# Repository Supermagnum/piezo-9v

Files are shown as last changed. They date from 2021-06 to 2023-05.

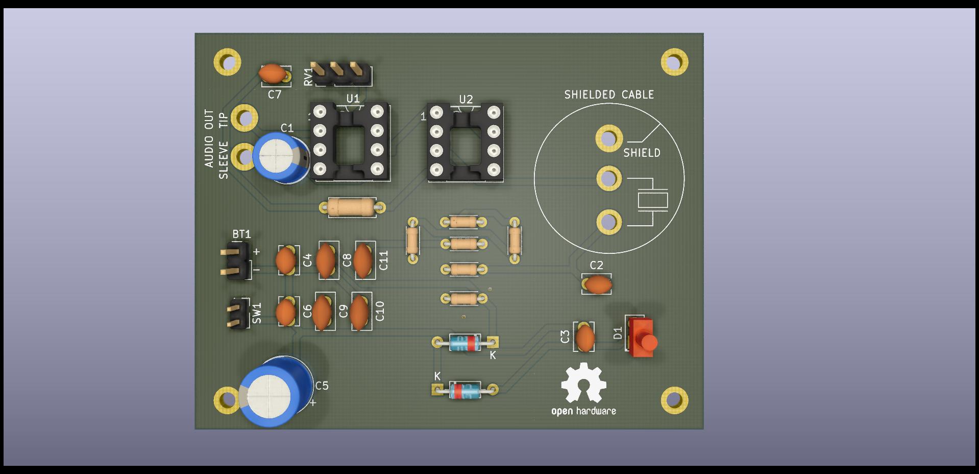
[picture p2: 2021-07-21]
9v-preamp-components.jpg

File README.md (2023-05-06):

# piezo-9v
A small PCB for pizoelectric amplifier, runs on 9V.
It should have battery capacity for around 5 hours.

It's fairly easy and straight forward to solder the components to the circuit board, a nice pointy soldering iron, solder,and a ohm or multimeter is all that is needed. 

Please use 0,5 W metal film resistors with 1% tolerance or better and audio quality capacitors.
C0G (NP0) or X7R capacitors is very good.

Of course one needs a suitable metal box, and the circuit boards components must not come in contact with the metal box. 
That will cause short circuit, so it's best mounted on conducting stand offs because the corner pads on the PCB board must be connected to the metal box.
Check that no one of the soldering pads has been bridged before applying power.

A shielded cable must be used to connect to the piezoelectric element.
NOTE:
It is my opinion that a shielded cable with 2 conductors inside is the best.
Suggested cable: Digi-Key Part Number: 30-01225-5-ND

The sensivity can be made adjustable if a rotary potentiometer is used to replace R7.
A nice one is : Digi-Key Part Number 310Y-001-103L-ND. 
Connect one end of the terminals to one of the R7 solder points, and the middle terminal to the other. 

It can be used for a reverb plate, listening to the insides of a engine,recording the sound of vibrating things. 
You will need one piezoelectric disk for that, mounted in a metal box made of thin metal. Non electric conductive super glue is useable for that. 
Just glue it to a flat surface. 
The piezoelectric disk should be electrically insulated from the metal box.

Picture of a piezoelectric disc, with red wire for positive polarity and black for negative: https://github.com/Supermagnum/piezo-balanced/blob/main/Piezo-element-6.jpg

Schematic diagram:
https://github.com/Supermagnum/piezo-9v/blob/main/9v-preamp.pdf
D1 is a LED that lights up when it's switched on.

Aisler PCB:
https://aisler.net/p/BZUXMWVU

Digikey part list:
https://github.com/Supermagnum/piezo-9v/blob/main/9vpiezo-digikey-BOM.csv
(does NOT include the PCB or the necessary two conductor shielded cable to the piezoelectric element)

Component side of PCB:
https://github.com/Supermagnum/piezo-9v/blob/main/front.jpg

Back side:
https://github.com/Supermagnum/piezo-9v/blob/main/back.jpg

Picture with sockets for the opamps, capacitators,resistors and diodes installed:
https://github.com/Supermagnum/piezo-9v/blob/main/9v-preamp-components.jpg

Gerber files:
https://github.com/Supermagnum/piezo-9v/tree/main/gerbers

Some methods of mounting a piezoelectric disk can be found here:
https://locusonus.org/wiki/index.php?page=Hydrophone.en
Use a metal box with thin walls.
Commercial ones uses kerosene oil, so olive oil or sunflower oil is a great alternative as it will not pollute the environment if any leaks occurs. Aquarium silicone can also be used.
For flowing water a streamlined bulb is best, it reduces flow noise.

Around 35 to 40 dB gain should be nice for hydrophone usage.

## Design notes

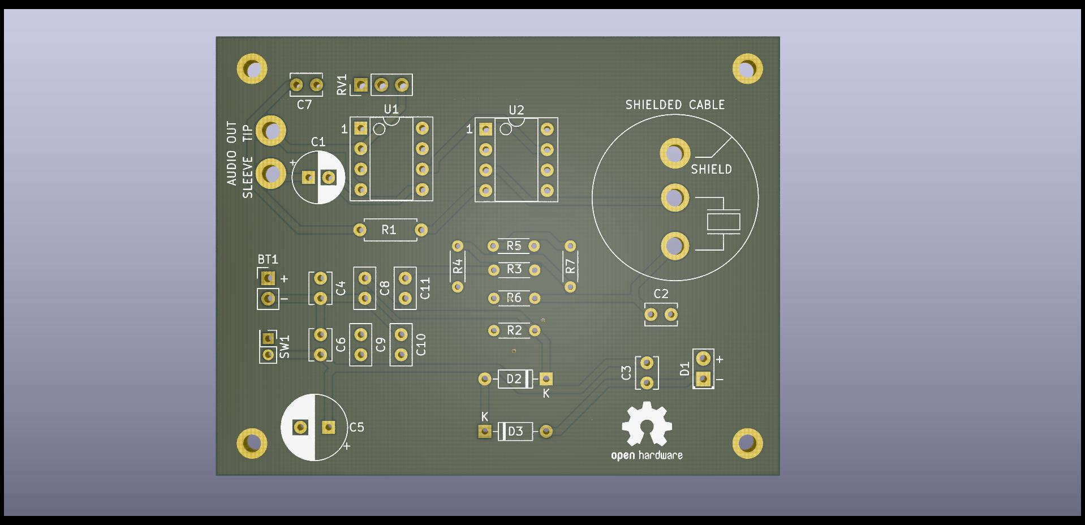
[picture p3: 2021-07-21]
front.jpg

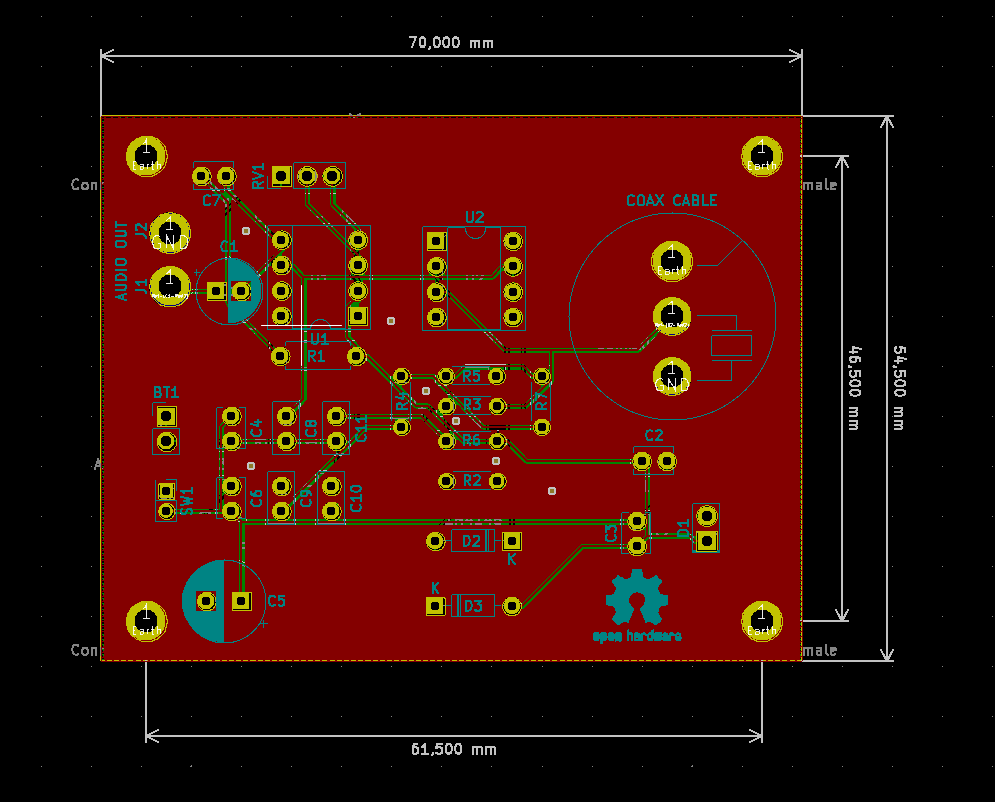
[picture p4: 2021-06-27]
Dimentions.png

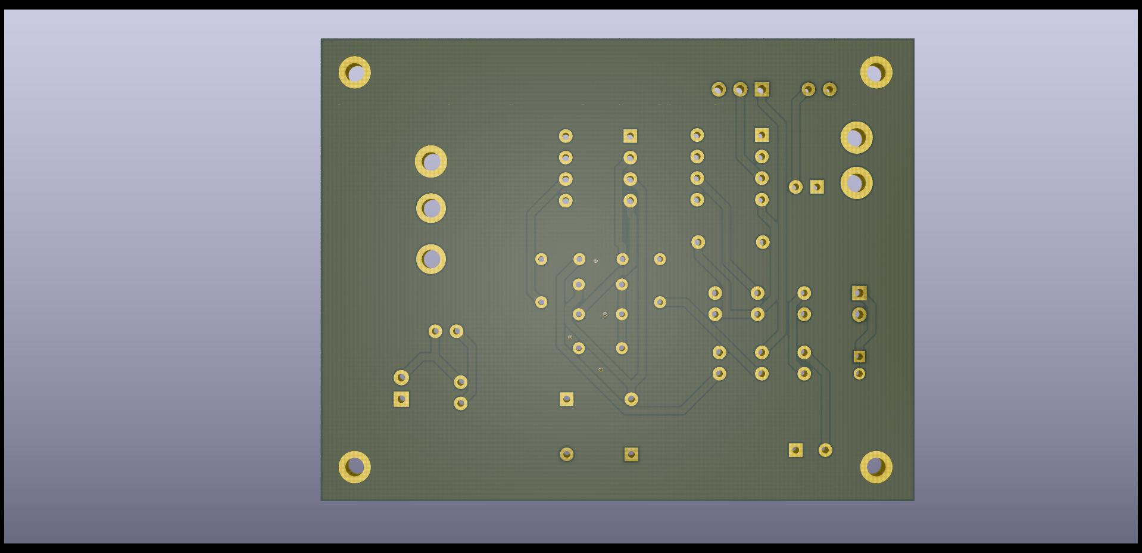
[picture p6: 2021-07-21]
back.jpg

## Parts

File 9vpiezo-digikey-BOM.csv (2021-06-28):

Index | Manufacturer Part Number | Manufacturer Name | Description | Attrition % | Requested Quantity 1 | Pack Quantity 1 | Pack Type 1 | Digi-Key Part Number 1 | Unit Price 1 | Extended Price 1 | Minimum Order Quantity 1 | Part Status
1 | NE5534P | Texas Instruments | IC OPAMP GP 1 CIRCUIT 8DIP |  | 1 | 1 | Tube | 296-7043-5-ND | 9,31000 | kr 9,31 | 1 | Active
2 | LM386N-4/NOPB | Texas Instruments | IC AMP CLASS AB MONO 1W 8DIP |  | 1 | 1 | Tube | 296-43960-5-ND | 11,16000 | kr 11,16 | 1 | Active
3 | P120PK-Y25BR10K | TT Electronics/BI | POT 10K OHM 1/20W PLASTIC LINEAR |  | 1 | 1 | Tray | 987-1710-ND | 5,79000 | kr 5,79 | 1 | Active
4 | 5100H7FL | Visual Communications Company - VCC | LED YELLOW 1/4" HOLE PANEL MOUNT |  | 1 | 1 | Bulk | L20697-ND | 38,01000 | kr 38,01 | 1 | Active
5 | 7105D | Electroswitch | SWITCH TOGGLE SPST 6A 125V |  | 1 | 1 | Bulk | 451-1158-ND | 31,63000 | kr 31,63 | 1 | Active
6 | FG22X5R1A476MNT06 | TDK Corporation | CAP CER 47UF 10V X5R RADIAL |  | 2 | 2 | Cut Tape (CT) | 445-173314-1-ND | 12,17000 | kr 24,34 | 1 | Active
7 | MRS16000C5602FCT00 | Vishay Beyschlag/Draloric/BC Components | RES 56K OHM 0.4W 1% AXIAL |  | 2 | 2 | Cut Tape (CT) | 56-MRS16000C5602FCT00CT-ND | 1,93000 | kr 3,86 | 1 | Active
8 | 1N4148-G | Comchip Technology | DIODE GEN PURP 75V 150MA DO35 |  | 2 | 2 | Cut Tape (CT) | 641-1313-1-ND | 1,43000 | kr 2,86 | 1 | Active
9 | C320C106K3R5TA | KEMET | CAP CER RAD 10UF 25V X7R 10% |  | 1 | 1 | Bulk | C320C106K3R5TA-ND | 29,20000 | kr 29,20 | 1 | Active
10 | C320C102K3G5TA | KEMET | CAP CER RAD 1NF 25V C0G 10% |  | 1 | 1 | Bulk | C320C102K3G5TA-ND | 3,61000 | kr 3,61 | 1 | Active
11 | PLV1D221MDL1TD | Nichicon | CAP ALUM POLY 220UF 20% 20V T/H |  | 1 | 1 | Cut Tape (CT) | 493-3861-1-ND | 23,66000 | kr 23,66 | 1 | Active
12 | CF12JT470R | Stackpole Electronics Inc | RES 470 OHM 1/2W 5% AXIAL |  | 1 | 1 | Cut Tape (CT) | CF12JT470RCT-ND | 0,84000 | kr 0,84 | 1 | Active
13 | RNF14FTD100R | Stackpole Electronics Inc | RES 100 OHM 1/4W 1% AXIAL |  | 1 | 1 | Cut Tape (CT) | RNF14FTD100RCT-ND | 0,84000 | kr 0,84 | 1 | Active
14 | RNF14FTD10R0 | Stackpole Electronics Inc | RES 10 OHM 1/4W 1% AXIAL |  | 1 | 1 | Cut Tape (CT) | RNF14FTD10R0CT-ND | 0,84000 | kr 0,84 | 1 | Active
15 | RL81V101MDN1KX | Nichicon | CAP ALUM POLY 100UF 20% 35V T/H |  | 1 | 1 | Cut Tape (CT) | 493-6630-1-ND | 17,79000 | kr 17,79 | 1 | Active
16 | FA16C0G2A104JRU06 | TDK Corporation | CAP CER 100NF 100V C0G/NP0 RAD |  | 1 | 1 | Cut Tape (CT) | 445-175390-1-ND | 10,49000 | kr 10,49 | 1 | Active
17 | FK20X7S1H475KR000 | TDK Corporation | CAP CER 4.7UF 50V X7S RADIAL |  | 1 | 1 | Bulk | 445-FK20X7S1H475KR000-ND | 7,47000 | kr 7,47 | 1 | Not For New Designs
18 | K104K10X7RF5UH5 | Vishay Beyschlag/Draloric/BC Components | CAP CER 0.1UF 50V X7R RADIAL |  | 1 | 1 | Cut Tape (CT) | BC2665CT-ND | 1,93000 | kr 1,93 | 1 | Active
19 | S503Z69Z5UL63L0R | Vishay Beyschlag/Draloric/BC Components | CAP CER 0.05UF 500V Z5U RADIAL |  | 1 | 1 | Bulk | BC5192-ND | 9,90000 | kr 9,90 | 1 | Active
20 | FG26X5R1E336MRT06 | TDK Corporation | CAP CER 33UF 25V X5R RADIAL |  | 1 | 1 | Cut Tape (CT) | 445-173432-1-ND | 8,56000 | kr 8,56 | 1 | Active
21 | HH-3449 | Bud Industries | BATTERY CONNECT SNAP 9V 6" LEADS |  | 1 | 1 | Bag | 377-1549-ND | 10,91000 | kr 10,91 | 1 | Active
22 | AB2025B-LW100-R | PUI Audio, Inc. | BUZZER ELEMENT STD 2.5KHZ 20MM |  | 2 | 2 | Bag | 668-1403-ND | 13,76000 | kr 27,52 | 1 | Active
23 | 1-2199298-2 | TE Connectivity AMP Connectors | CONN IC DIP SOCKET 8POS TIN |  | 2 | 2 | Tube | A120347-ND | 1,51000 | kr 3,02 | 1 | Active
24 | VR25000001004FA500 | Vishay Beyschlag/Draloric/BC Components | RES 1M OHM 1% 1/4W AXIAL |  | 1 | 1 | Cut Tape (CT) | BC4867CT-ND | 3,52000 | kr 3,52 | 1 | Active
25 | MBA02040C4701FCT00 | Vishay Beyschlag/Draloric/BC Components | RES 4.7K OHM 0.4W 1% AXIAL |  | 1 | 1 | Cut Tape (CT) | BC3275CT-ND | 1,85000 | kr 1,85 | 1 | Active
26 | MJ-3536N | CUI Devices | CONN JACK MONO 3.5MM R/A |  | 1 | 1 | Bag | CP-3536N-ND | 6,80000 | kr 6,80 | 1 | Active

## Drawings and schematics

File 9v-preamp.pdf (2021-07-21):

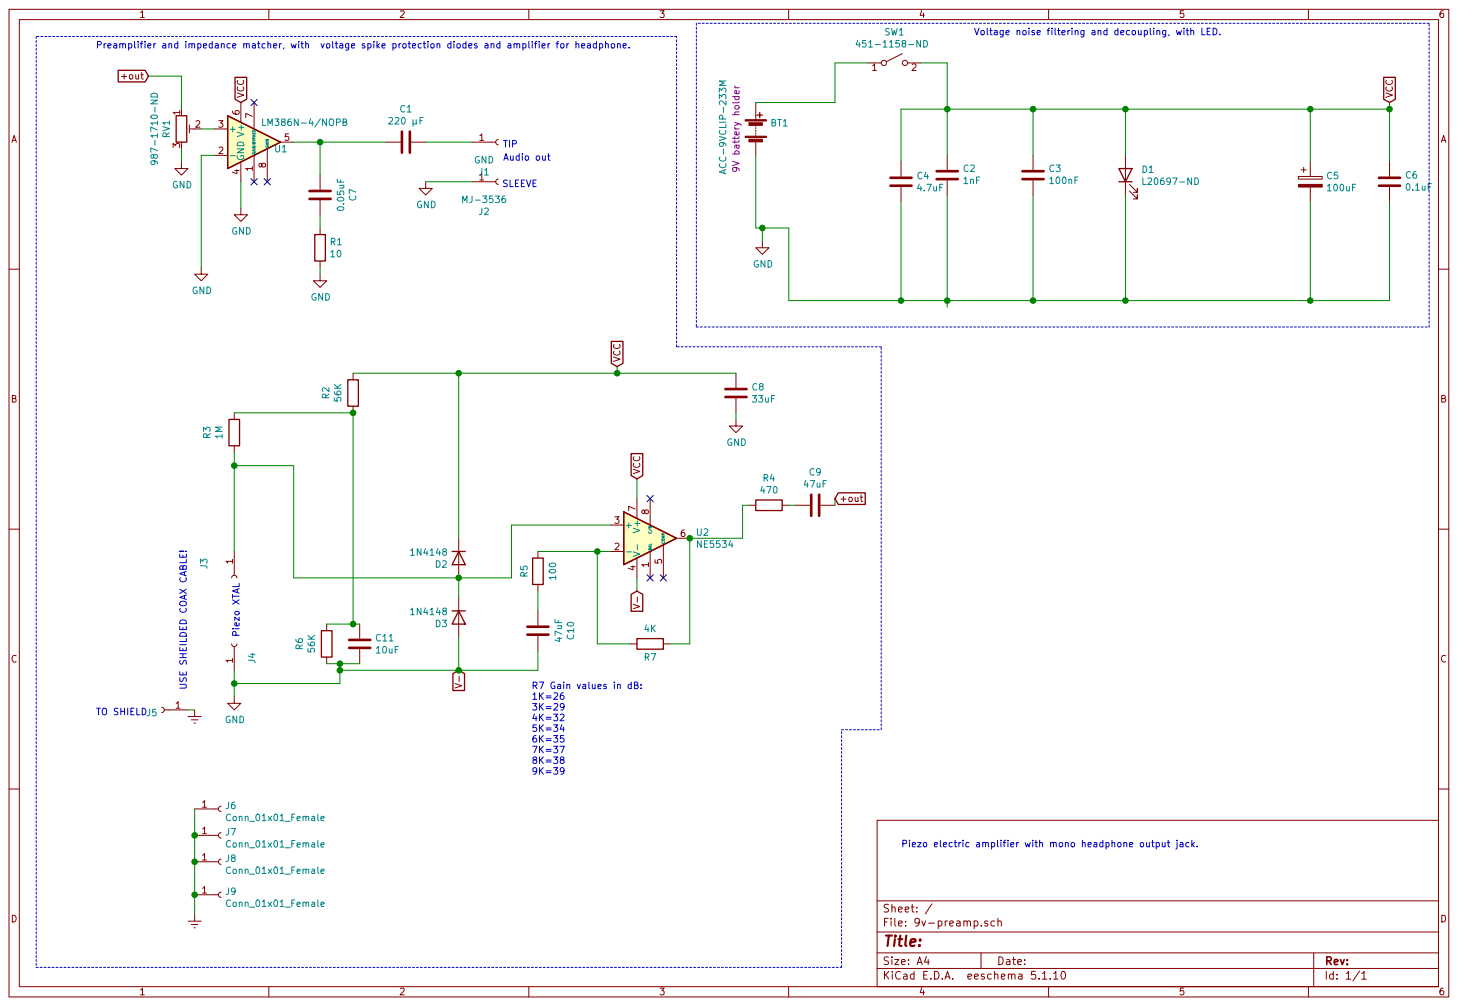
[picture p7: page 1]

Preamplifier and impedance matcher, with voltage spike protection diodes and amplifier for headphone. Piezo XTAL

Piezo electric amplifier with mono headphone output jack.

File: 9v-preamp.sch Sheet: /
Id: 1/1 Title:

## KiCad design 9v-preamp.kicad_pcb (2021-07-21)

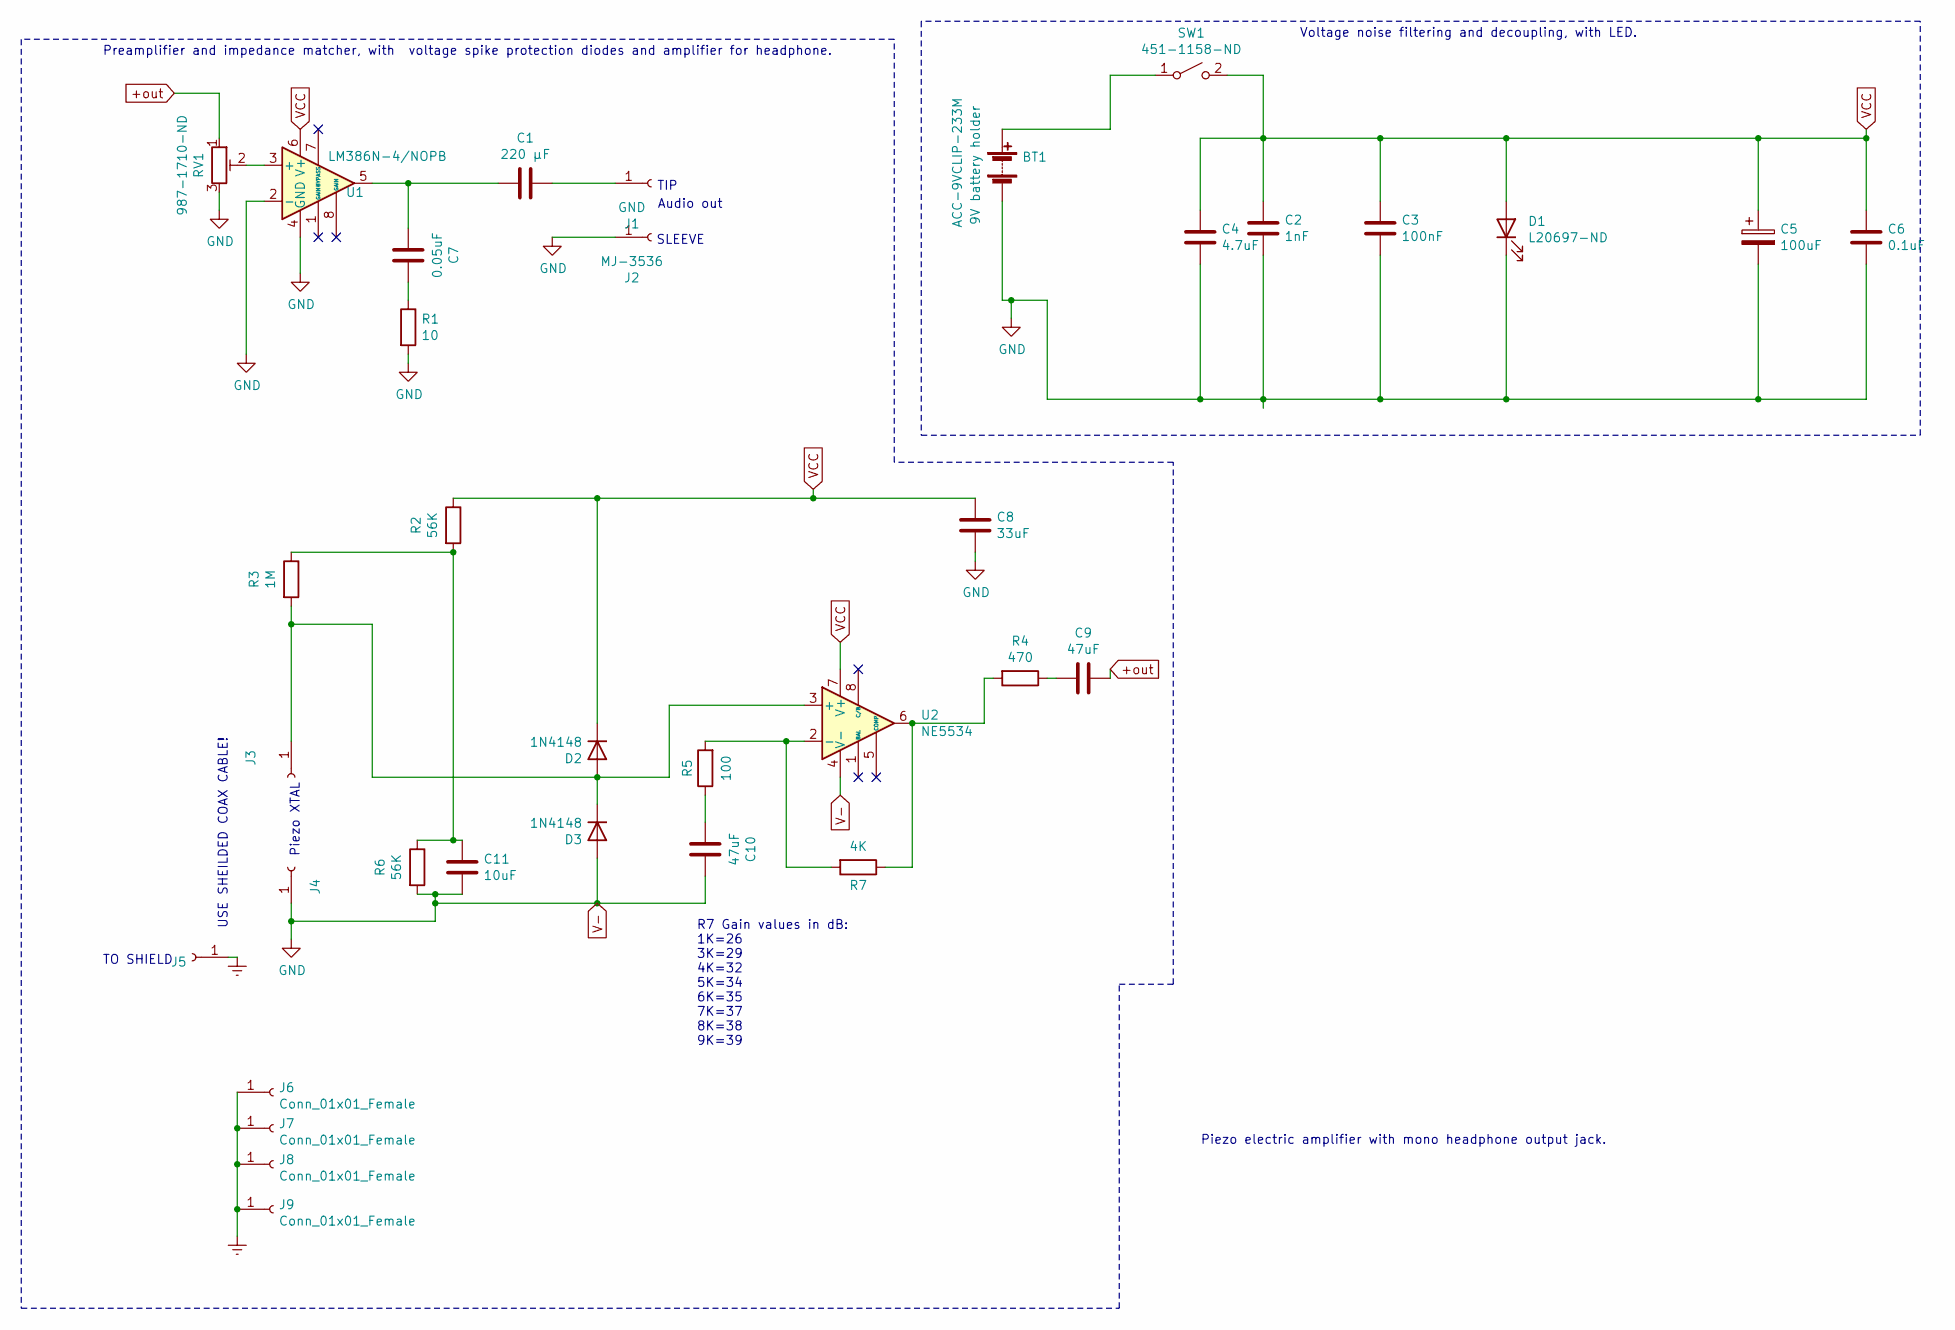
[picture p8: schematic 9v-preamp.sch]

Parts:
BT1: ACC-9VCLIP-233M; PinHeader_1x02_P2.54mm_Vertical
C1: 220 µF; CP_Radial_D6.3mm_P2.50mm
C2: 1nF; C_Disc_D3.8mm_W2.6mm_P2.50mm
C3: 100nF; C_Disc_D3.8mm_W2.6mm_P2.50mm
C4: 4.7uF; C_Disc_D3.8mm_W2.6mm_P2.50mm
C5: 100uF; CP_Radial_D8.0mm_P3.50mm
C6: 0.1uF; C_Disc_D3.8mm_W2.6mm_P2.50mm
C7: 0.05uF; C_Disc_D3.8mm_W2.6mm_P2.50mm
C8: 33uF; C_Disc_D5.0mm_W2.5mm_P2.50mm
C9, C10: 47uF; C_Disc_D5.0mm_W2.5mm_P2.50mm
C11: 10uF; C_Disc_D5.0mm_W2.5mm_P2.50mm
D1: L20697-ND; LED_D2.0mm_W4.8mm_H2.5mm_FlatTop
D2, D3: 1N4148; D_DO-35_SOD27_P7.62mm_Horizontal
J1: GND; MountingHole_2.2mm_M2_DIN965_Pad
J2: MJ-3536; MountingHole_2.2mm_M2_DIN965_Pad
J3, J4: Conn_01x01_Female; MountingHole_2.2mm_M2_ISO7380_Pad
J5, J6, J7, J8, J9: Conn_01x01_Female; MountingHole_2.2mm_M2_DIN965_Pad
R1: 10; R_Axial_DIN0207_L6.3mm_D2.5mm_P7.62mm_Horizontal
R2, R6: 56K; R_Axial_DIN0204_L3.6mm_D1.6mm_P5.08mm_Horizontal
R3: 1M; R_Axial_DIN0204_L3.6mm_D1.6mm_P5.08mm_Horizontal
R4: 470; R_Axial_DIN0204_L3.6mm_D1.6mm_P5.08mm_Horizontal
R5: 100; R_Axial_DIN0204_L3.6mm_D1.6mm_P5.08mm_Horizontal
R7: 4K; R_Axial_DIN0204_L3.6mm_D1.6mm_P5.08mm_Horizontal
RV1: 987-1710-ND; PinHeader_1x03_P2.54mm_Vertical
SW1: 451-1158-ND; PinHeader_2x01_P2.00mm_Vertical
U1: LM386N-4/NOPB; DIP-8_W7.62mm_Socket
U2: NE5534; DIP-8_W7.62mm_Socket

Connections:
+out: C9.1, RV1.1
Earth: J5.1, J6.1, J7.1, J8.1, J9.1
unnamed: BT1.1 (+), SW1.1 (A)
unnamed: C1.1, J1.1
unnamed: C1.2, C7.2, U1.5
unnamed: C7.1, R1.1
unnamed: C9.2, R4.1
unnamed: C10.2, R5.1
unnamed: C11.1, R2.2, R3.1, R6.1
unnamed: D2.2 (A), D3.1 (K), J3.1, R3.2, U2.3 (+)
unnamed: R4.2, R7.1, U2.6
unnamed: R5.2, R7.2, U2.2 (-)
unnamed: RV1.2, U1.3 (+)
V-: BT1.2 (-), C2.1, C3.1, C4.2, C5.2, C6.1, C8.2, C10.1, C11.2, D1.1 (K), D3.2 (A), J2.1, J4.1, R1.2, R6.2, RV1.3, U1.2 (-), U1.4 (GND), U2.4 (V-)
VCC: C2.2, C3.2, C4.1, C5.1, C6.2, C8.1, D1.2 (A), D2.1 (K), R2.1, SW1.2 (B), U1.6 (V+), U2.7 (V+)

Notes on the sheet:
Piezo electric amplifier with mono headphone output jack.
Audio out
TIP
SLEEVE
Piezo XTAL
R7 Gain values in dB: 1K=26 3K=29 4K=32 5K=34 6K=35 7K=37 8K=38 9K=39
USE SHEILDED COAX CABLE!
TO SHIELD
Voltage noise filtering and decoupling, with LED.
Preamplifier and impedance matcher, with voltage spike protection diodes and amplifier for headphone.

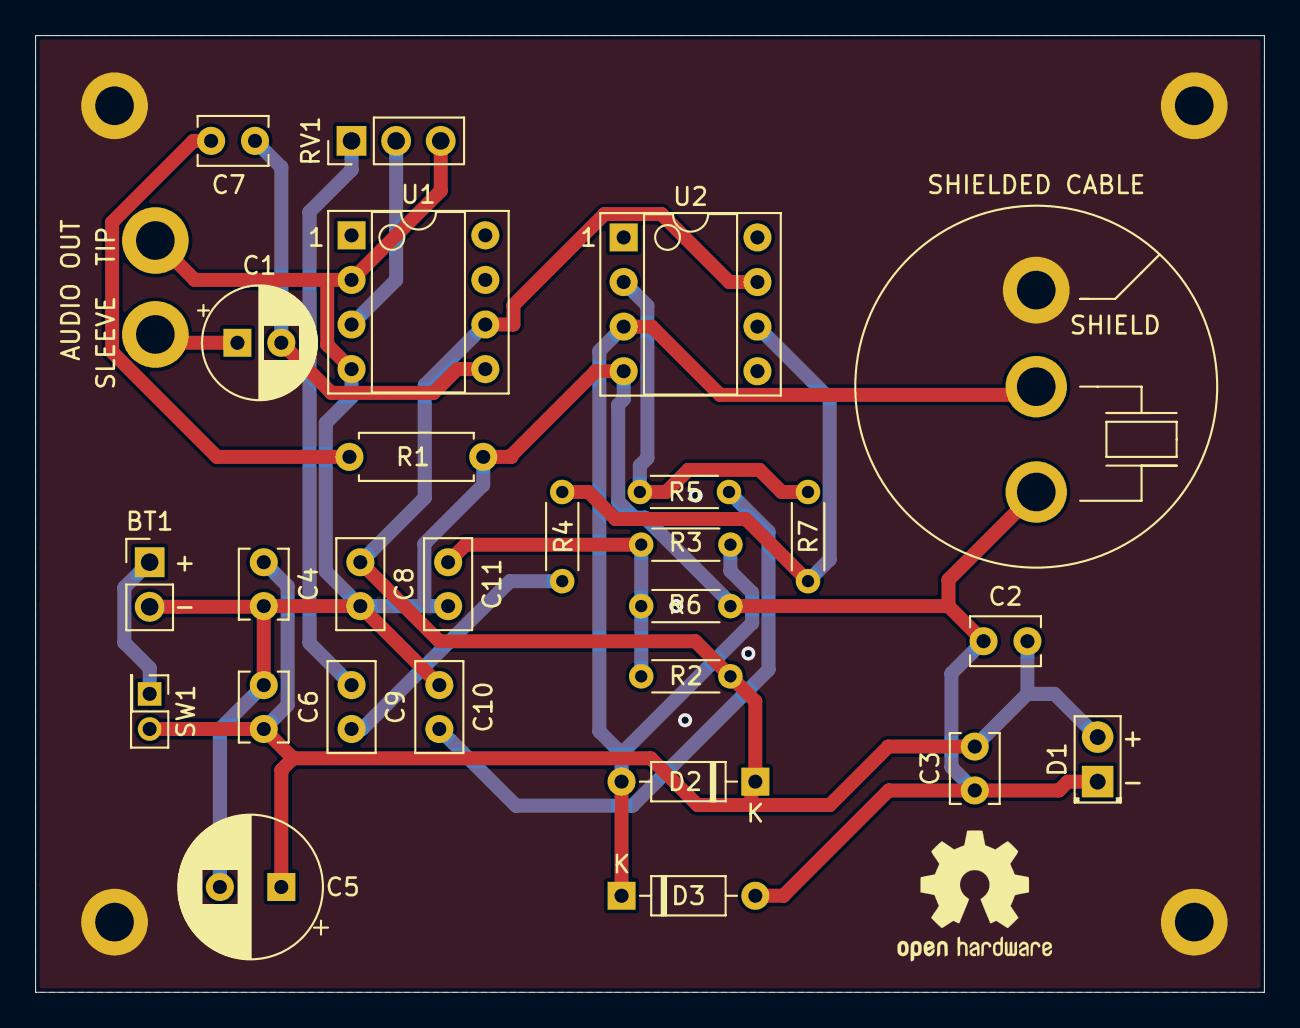
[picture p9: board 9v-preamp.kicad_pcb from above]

Board: 2 copper layers, 70.0 x 54.5 mm, 35 parts (0 on the bottom side), 15 nets.

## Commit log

2021-06-28 Add files via upload
    updated files, turned U1 around so It faces the same way as U2.
    [9v-preamp-B_Cu.gbr, 9v-preamp-B_Mask.gbr, 9v-preamp-B_Paste.gbr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]
2021-06-28 Added digikey part list.
    [9vpiezo-digikey-BOM.csv]
2021-07-02 Add files via upload
    corrected missing connection to VCC.
    [9v-preamp-B_Cu.gbr, 9v-preamp-B_Mask.gbr, 9v-preamp-B_Paste.gbr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]
2021-07-21 Add files via upload
    Added + and - marks on the LED solder connections, and pin 1 on the op amps.
    [9v-preamp-B_Cu.gbr, 9v-preamp-B_Mask.gbr, 9v-preamp-B_Paste.gbr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]
